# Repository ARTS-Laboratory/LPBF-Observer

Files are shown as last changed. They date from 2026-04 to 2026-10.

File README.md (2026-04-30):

# LPBF-Observer
Hardware and software designs for in situ systems for laser-based powder bed fusion additive manufacturing.

<p align="center">
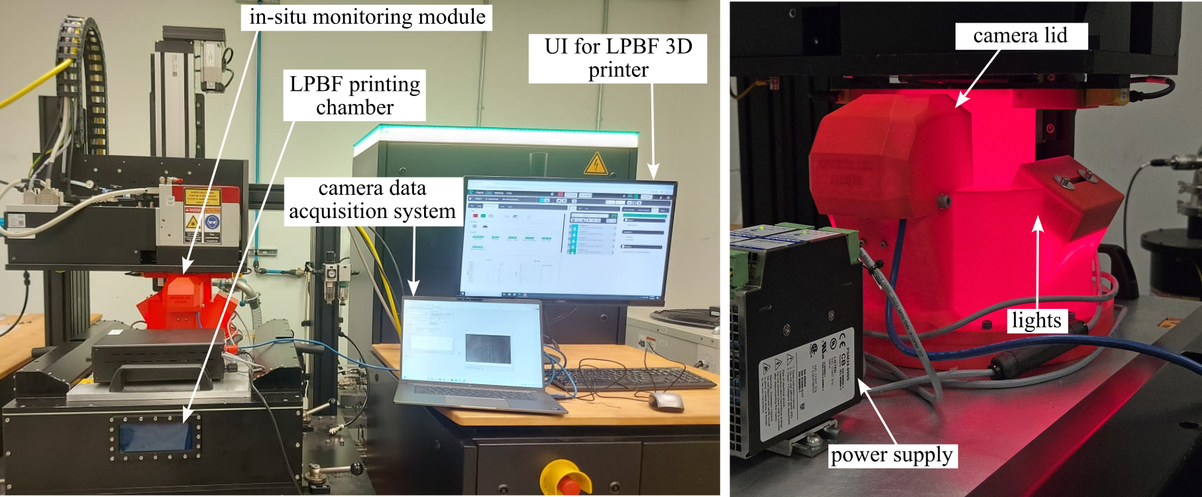
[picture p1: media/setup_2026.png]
 <br> 
The laser vibrometer setup of in situ systems for laser-based powder bed fusion additive manufacturing.  
</p>

## [System Development](system_development)
The system (hardware and software) design for the project.

## [General Use](general_use)
Basic accessories for the system that can be used with any of the covers.

## Licensing and Citation

This work is licensed under a Creative Commons Attribution-ShareAlike 4.0 International License [cc-by-sa 4.0].



#### Bibtex

@Misc{ARTSLabSituMonitoringPowder,  
  author = {{ARTS-L}ab},  
  title  = {{LPBF}-Observer},  
  groups = {{ARTS-L}ab},  
  note = {Accessed: 20xx-xx-xx},  
  url    = {https://github.com/ARTS-Laboratory/LPBF-Observer},  
}  

<p align="center">
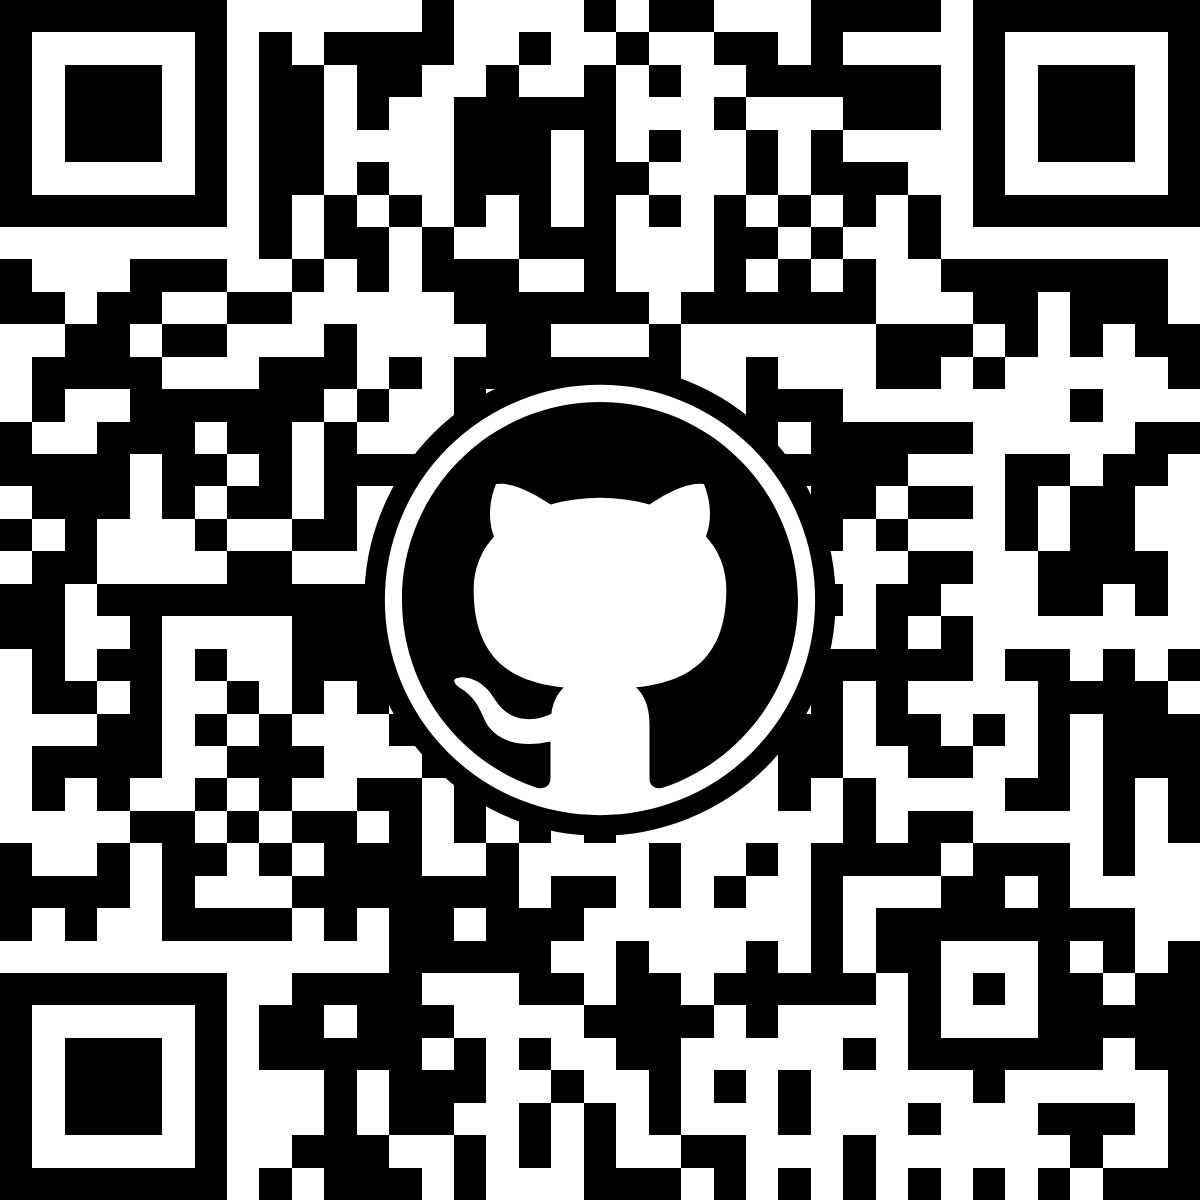
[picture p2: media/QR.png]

</p>
<p align="center">
QR code for repo.
</p>

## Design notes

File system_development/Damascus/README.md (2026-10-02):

# Damascus
Sensing system designed with multiple sensing systems.

## V0.1.0
Dual vision holder designed for thermal and optical cameras 

## V0.2.0
Dual vision holder designed for optical and event cameras 

## V0.3.0
Triple vision holder desinged for optical, thermal, and event cameras 

## V0.4.0
Dual vision holder designed to take a mixture of cameras

## V0.5.0
A more refined dual vision holder designed to take a mixture of cameras
## V0.5.1
Adding distinct software controls for variations of the Damascus setup.

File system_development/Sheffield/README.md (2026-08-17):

# Sheffield
An in situ sensing system with a laser vibrometer.

## V0.1.0 - Exploriotority 
Initial hardware design for in situ monitoring system.

## V0.2.0 - System Built as Sub-components
Initial hardware design for in situ monitoring system.

## V0.3.0 - First Single Prototype
Combining the sub-components of V0.2 into a single hardware design. 

## V0.4.0 
First clean version of a semi-stable lid.

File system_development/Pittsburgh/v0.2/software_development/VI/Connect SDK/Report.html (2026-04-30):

Import Shared Library Report

Friday, May 16, 2025 3:06:13 PM

Your generated files are installed in the following folder:
C:\Users\mayhe\OneDrive\Documents\GitHub\In-situ-monitoring-of-powder-bed-fusion-additive-manufacturing\system_development\Orichalcum\v0.2\Software_design\thermal-camera\VI\Connect SDK

Parsing header file warnings:
No errors/warnings occurred when parsing the header file.

The following errors/warnings occurred when generating the wrapper VIs for this shared library.

Cannot create VI
The following VI cannot be created. This might indicate that the associated function contains parameters of a data type that cannot be converted directly. To work around this issue, you can create a custom control or typedef control to represent a complex structure or multidimensional array, then re-run the Import Shared Library wizard and select Update VIs from a shared library. Using the same shared library, step through the wizard again. On the Configure VIs and Controls page, assign the custom control or typedef to the associated parameter(s). Complex structures include nested structures, structures containing arrays, arrays of strings, and multidimensional arrays.
Get Fixed Emissivity.vi
Init Imager IPC.vi
Release Imager IPC.vi
Run Imager IPC.vi
Set Fixed Emissivity.vi
Set Imager IPC Count.vi

VI Not Executable
The VI is not executable because of one of the following reasons:
1. The shared library or a dependent file is not installed. To make the VI executable, you must install the shared library and all support files on the computer on which you run the VI.
2. A required custom control might be empty or cannot be found. To make the VI executable, update the custom control manually.
3. The VI contains a parameter with an unsupported data type. To make the VI executable, you must replace the empty cluster that the wizard generates with a control or indicator that uses supported data types.
Set Callback On Areas Init.vi
Set Callback On Config Changed.vi
Set Callback On Frame Init.vi
Set Callback On Init Completed.vi
Set Callback On LS Slit Center Line.vi
Set Callback On New Frame.vi
Set Callback On New Visible Frame.vi
Set Callback On Play Metadata.vi
Set Callback On Server Stopped.vi
Set Callback On Visible Frame Init.vi

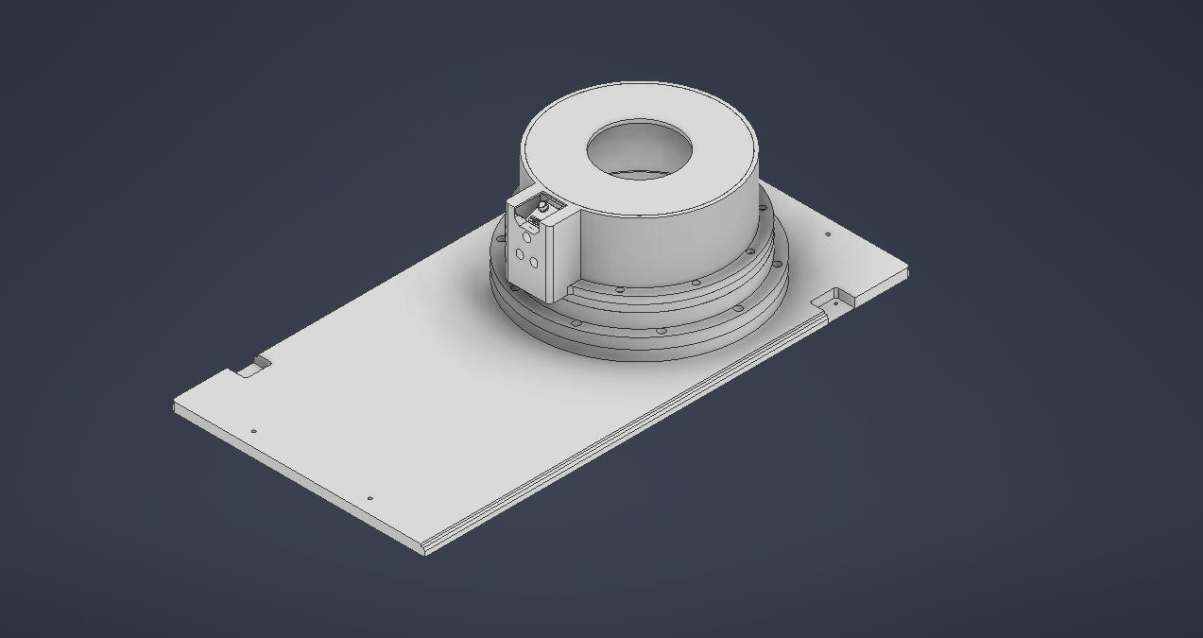
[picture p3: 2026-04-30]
system_development/Birmingham/media/Optical Camera Only.png

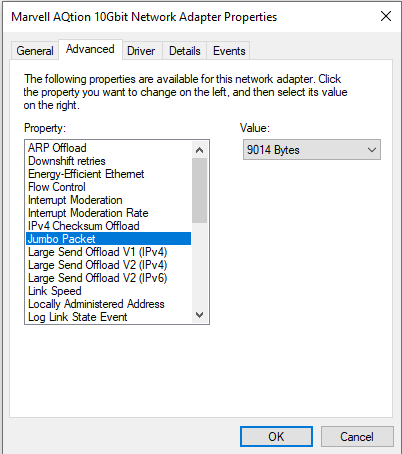
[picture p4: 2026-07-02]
system_development/Damascus/V0.5.1/software development/event_optical/iteration_2/Media/JumboPacket.png

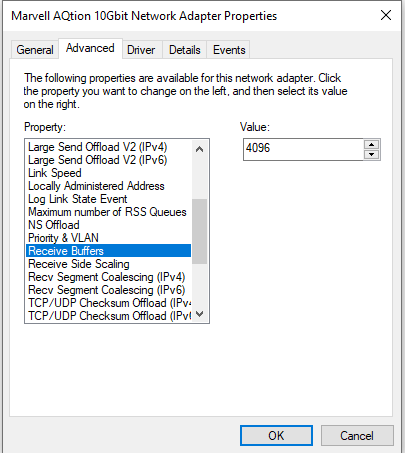
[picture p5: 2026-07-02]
system_development/Damascus/V0.5.1/software development/event_optical/iteration_2/Media/ReceiveBuffers.png

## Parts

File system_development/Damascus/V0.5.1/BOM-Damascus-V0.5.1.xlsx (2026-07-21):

Internal Part Name | MFR / Vendor Description | MFR Part Number | Amount Per Cover | Individual Cost | Total Cost | Notes | Vendor 1 | Vendor 2 | Vendor 3 | Vendor 4 | Vendor 5 | Vendor 6
Aluminum Cover |  |  | 1 | $800.00 | $800.00 | Custom order from Xometry | https://www.xometry.com/
handle | JW WINCO Pull Handle: Unthreaded Holes, Plastic, Black, 1/4 in/5/16 in/M6/M8 Screw Size, 0.32 in | 6333220 | 2 | $12.70 | $25.40 |  | https://www.grainger.com/product/JW-WINCO-Pull-Handle-Unthreaded-Holes-813RC8
rubber seal | Rubber Cord: Buna-N, Round C.S. Shape, 3 mm C.S., 100 ft Overall Lg | CSBUNA-3.0-100 | 1 | $73.29 | $73.29 |  | https://www.grainger.com/product/Rubber-Cord-Buna-N-848F88
Seal Glass Ring |  |  |  |  | $0.00
Cylinder Housing |  |  |  |  | $0.00
Camera Lid |  |  |  |  | $0.00
Cylinder Segment Inner |  |  |  |  | $0.00
Cylinder Segment Outer |  |  |  |  | $0.00
Magnet Sensors | PILZ PSEN 2.1-10 512110 V1.1 |  |  |  | $0.00
M6x14 Socket Head Screw | Socket Head Cap Screw: M6x1.00 Thread Size, 14 mm Lg, Std, Plain, Stainless Steel, 18-8, 50 PK | M51050.060.0014 | 1 | $4.70 | $4.70 |  | https://www.grainger.com/product/Socket-Head-Cap-Screw-M6x1-26WC46
M6x20 Bolt | Socket Head Cap Screw: M6x1.00 Thread Size, 20 mm Lg, Std, Plain, Stainless Steel, 18-8, 50 PK | M51050.060.0020 | 1 | $7.58 | $7.58 |  | https://www.grainger.com/product/Socket-Head-Cap-Screw-M6x1-26WC48
M6 ID 12mm OD Washer | Flat Washer: 18-8, Stainless Steel, M6 Screw Sz, 6.62 mm In Dia, 12 mm Out Dia, 18-8, 50 PK | M51420.060.0001 | 1 | $1.54 | $1.54 |  | https://www.grainger.com/product/Flat-Washer-18-8-26WC34
M6 Nut | Hex Nut: Std Hex, M6x1.00 Thread, 10 mm Hex Wd, 5 mm Hex Ht, Stainless Steel, 18-8, Plain, 50 PK | M51080.060.0001 | 1 | $2.95 | $2.95 |  | https://www.grainger.com/product/Hex-Nut-Std-Hex-22YK33
M5x40 Bolt |  |  |  |  | $0.00
M5 ID 9.8mm OD Washer |  |  |  |  | $0.00
M4x14 Bolt |  |  |  |  | $0.00
M4 ID 8.8mm OD Washer |  |  |  |  | $0.00
M3x25 Bolt |  |  |  |  | $0.00
M3x10 Pan Head Bolt |  |  |  |  | $0.00
M3 Washer |  |  |  |  | $0.00
M3 Nuts |  |  |  |  | $0.00
USB hub | Eaton Tripp Lite Series 4-Port Industrial-Grade USB 3.x (5Gbps) Hub - 20 kV ESD Immunity, Metal Housing, Mountable | U360-004-IND | 1 | $110.00 | $110.00 |  | https://www.cdwg.com/product/tripp-lite-4-port-industrial-usb-3.0-superspeed-hub-15kv-esd-immunity-metal/3682489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
relays | RELAY GEN PURPOSE SPST 6A 24V | 2903361 | 2 | $9.46 | $18.92 |  | https://www.digikey.com/en/products/detail/phoenix-contact/2903361/4755334
USB-C to USB-A Adapter | Eaton Tripp Lite Series USB 3.0 Adapter Converter USB-A to USB Type C M/F USB-C - USB-C adapter - USB A to 24 pin USB-C | U329-000 | 1 | $13.96 | $13.96 |  | Eaton Tripp Lite Series USB 3.0 Adapter Converter USB-A to USB Type C M/F USB-C - USB-C adapter - USB A to 24 pin USB-C - U329-000 - USB Adapters - CDWG.com (https://www.cdwg.com/product/tripp-lite-usb-3.0-adapter-converter-usb-a-to-usb-type-c-m-f-usb-c/5238658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)
Light | 2X3 SPOT LIGHT | AL143W-625IC | 2 | $695.33 | $1390.66 | Used off Ebay is a good source | CIMTEC Automation
Eathnet hub power sully | AC or DC DIN Rail Power Supply 1 Output 48V 1.6A | XDR-75E-48 | 1 | $23.00 | $23.00 |  | https://www.digikey.com/en/products/detail/mean-well-usa-inc/XDR-75E-48/26080802
2.5G PoE++ DIN-Rail Switch | TRENDnet TI-BG50611 6-Port Industrial 2.5G PoE++ DIN-Rail Switch with 10G Ports | TI-BG50611 | 1 | $329.00 | $329.00 |  | https://www.newegg.com/trendnet-ti-bg50611/p/0XP-001A-009D1?Item=9SIAHFEKFX4055
switch to thunderbold patch cable | Eaton Tripp Lite Series Cat6a 10G Snagless Shielded Slim STP Ethernet Cable (RJ45 M/M), PoE, Blue, 3 ft. (0.9 m) | 7175130 | 1 | $8.47 | $8.47 |  | https://www.cdwg.com/product/eaton-tripp-lite-series-cat6a-10g-snagless-shielded-slim-stp-ethernet-cable/7175130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
10 GBE to Thunderbolt adapter | OWC Thunderbolt 4 10G Ethernet Adapter | OWCTB4ADP10GBE | 1 | $181.53 | $181.53 |  | https://www.cdwg.com/product/owc-thunderbolt-4-10g-ethernet-adapter/8482162
2M Thunderbolt cable | OWC 2.0M (78") Thunderbolt 4 (USB-C) Cable for Thunderbolt And USB-C Devices - Black | OWCCBLTB4C2.0M | 1 | $49.29 | $49.29 |  | https://www.cdwg.com/product/owc-2.0m-78-thunderbolt-4-usb-c-cable-for-thunderbolt-and-usb-c-device/7390529
1M Thunderbolt cable | OWC 1.0M (39.4") Thunderbolt 5 (USB-C) Cable Black for Thunderbolt And USB-C Devices - Black | OWCCBLTB5C1.0M | 1 | $30.51 | $30.51 |  | https://www.cdwg.com/product/owc-1.0m-39.4-thunderbolt-5-usb-c-cable-black-for-thunderbolt-and-usb/8269345
Thermal Camera | Optris Xi 400 thermal camera, 382 x 288, 18 deg x 14 deg lens, f = 20 mm | OPTXI40LTF20T090 | 1 | $2995.00 | $2995.00 | Optional thermal-imaging configuration from paper; includes PIX Connect software/cables per vendor listing. | https://www.tequipment.net/Optris/XI400-18x14/Scientific-Thermal-Imagers/ | https://optris.com/us/products/thermal-cameras/compact-line/xi-400/ | https://www.newark.com/optris/optxi40ltf20t090/thermal-imager-382-x-288-20mm/dp/70AJ6214
Optical Camera - USB3 | BFS-U3-200S6M-C USB 3.1 Blackfly S monochrome camera, 20 MP, 1 in Sony IMX183, C-Mount | BFS-U3-200S6M-C | 1 | $700.00 | $700.00 | Primary optical camera from paper; note that camera accessories/cables may be sold separately. | https://www.edmundoptics.com/p/BFS-U3-200S6M-C-USB3-Blackflyreg-S-Monochrome-Camera/40177/ | https://www.digikey.com/en/products/detail/flir-integrated-imaging-solutions-inc/BFS-U3-200S6M-C/16528419
Optical Camera - GigE/PoE Alternate | BFS-PGE-200S6M-C PoE GigE Blackfly S monochrome camera, 20 MP, 1 in Sony IMX183, C-Mount | BFS-PGE-200S6M-C | 1 | $700.00 | $700.00 | Optional alternate from supplied eBay link; set Amount Per Cover to 1 if selecting the PoE/GigE camera instead of USB3. | https://www.edmundoptics.com/p/bfs-pge-200s6m-c-poe-gige-blackflyr-s-monochrome-camera/40195/ | https://www.ebay.com/itm/388858412191 | https://www.digikey.com/en/products/detail/flir-integrated-imaging-solutions-inc/BFS-PGE-200S6M-C/16528297
35 mm Lens - 1 in Sensor | Edmund Optics 35 mm focal length HP Series fixed focal length lens, C-Mount, f/1.8, 1.1 in max sensor format | 86-573 | 1 | $660.00 | $660.00 | Primary high-resolution optical lens for the 1 in/20 MP camera; supplied eBay 86573 listing maps to Edmund stock #86-573. | https://www.edmundoptics.com/p/35mm-focal-length-hp-series-fixed-focal-length-lens/28992/ | https://www.ebay.com/itm/334656600752
35 mm Lens - 2/3 in Alternate | Edmund Optics 35 mm C Series fixed focal length lens, C-Mount, f/1.65, 2/3 in max sensor format | 59-872 | 1 | $374.00 | $374.00 | Optional older/used lens from duplicate eBay link; not counted in total unless selected. eBay sold listing showed $49.99. | https://www.edmundoptics.com/p/35mm-c-series-fixed-focal-length-lens/16529/ | https://www.ebay.com/itm/377073297097
Lens Step-Up Adapter | Midwest Optical Systems Step-Up Adapter M25.5-M37 | SU25.5-37 | 1 | $30.00 | $30.00 | Use with the #59-872 C Series lens to mount M37 filters; not needed for the #86-573 HP lens with native M37 thread. | https://machinevisiondirect.com/products/midopt-su25_5-37?variant=37662128013502
Bandpass Filter - Dark Red 660 nm | Midwest Optical Systems BP660-37 dark red bandpass filter, M37 x P0.75 | BP660-37 | 1 | $151.00 | $151.00 | Paper-specified dark red bandpass filter; use with 650-680 nm red lighting. | https://machinevisiondirect.com/products/mid-bp660-37 | https://midopt.com/filters/bp660/
Bandpass Filter - Light Red 635 nm | Midwest Optical Systems BP635-37 light red bandpass filter, M37 x P0.75 | BP635-37 | 1 | $151.00 | $151.00 | Optional light-red filter from supplied link; set Amount Per Cover to 1 for 615-645 nm lighting. | https://machinevisiondirect.com/products/mid-bp635-37 | https://midopt.com/filters/bp635/
37 mm UV Protective Lens Filter | Tiffen UV Protector Filter, 37 mm | 37UVP | 1 | $9.99 | $9.99 | Plain protective UV filter for 37 mm lens/filter thread | Tiffen
 |  |  |  | Total | $8841.79

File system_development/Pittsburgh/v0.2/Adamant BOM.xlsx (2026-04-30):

Name | Quantity | Source
Aluminum Cover | 1 | Xometry + model
Pull Handle | 2 | https://www.grainger.com/product/JW-WINCO-Pull-Handle-Unthreaded-Holes-813RC8
Horsehoe | 1 | Xometry + model
Head Plate (metal) | 1 | Xometry + model
Welding glass | 1 | Laser Vision (https://lasersafety.com/product/p5p10-window/) | Glass1 (https://www.mscdirect.com/product/details/62674445) | Glass2 (https://www.mscdirect.com/product/details/62674403) | Glass3 (https://www.mscdirect.com/product/details/62674437) | Glass4 (https://www.mscdirect.com/product/details/62674411)
Xi 400 20mm | 1 | optris
Seal Glass Ring | 1 | 3D Printed
Cylinder Housing | 1 | 3D Printed
Camera Lid | 1 | 3D Printed
Cylinder Segment Inner | 1 | 3D Printed
Cylinder Segment Outer | 1 | 3D Printed
Magnet Sensors | 4 | Aconity
M6x15 | 2
M6x20 | 5
M6 ID 11.8mm OD Washer | 7
M6 Nut | 3
M5x40 | 12
M5x20 | 1
M5 ID 9.8mm OD Washer | 16
M5 Nut | 4
M4x14 | 11
M4 ID 8.8mm OD Washer | 11
Rubber Seal (100ft) | 1 | https://www.grainger.com/product/Rubber-Cord-Buna-N-848F88

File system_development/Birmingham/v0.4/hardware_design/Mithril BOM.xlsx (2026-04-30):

Name | Quantity | Source
Aluminum Cover | 1 | Xometry + model
Pull Handle | 2 | https://www.grainger.com/product/JW-WINCO-Pull-Handle-Unthreaded-Holes-813RC8
Head Plate (metal) | 1 | Xometry + model
FLIR Blackfly Camera | 1
Edmunds Optis 25mm Lens | 1
Seal Glass Ring | 1 | 3D Printed
Cylinder Housing | 1 | 3D Printed
Camera Lid | 1 | 3D Printed
Cylinder Segment Inner | 1 | 3D Printed
Cylinder Segment Outer | 1 | 3D Printed
Magnet Sensors | 4 | Aconity
M6x15 Bolt | 2
M6x20 Bolt | 4
M6 ID 11.8mm OD Washer | 6
M6 Nut | 2
M5x40 Bolt | 12
M5 ID 9.8mm OD Washer | 15
M4x14 Bolt | 11
M4 ID 8.8mm OD Washer | 11
M3x25 Bolt | 3
M3x10 Pan Head Bolt | 4
M3 Washer | 4
M3 Nuts | 4
Rubber Seal (100ft) | 1 | https://www.grainger.com/product/Rubber-Cord-Buna-N-848F88

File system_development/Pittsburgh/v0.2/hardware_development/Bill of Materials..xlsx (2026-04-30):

Name | Quantity | Source 1 | Source 2 | Source 3
Cover | 1 | Xometry + model
300mm Housing 1 | 1 | 3D Printed
300mm Housing 2 | 1 | 3D Printed
Cylinder Spacer | 1 | 3D Printed
Cylinder Segment Inner | 1 | 3D Printed
Cylinder Segment Outer | 1 | 3D Printed
Cylinder Segment 1 | 1 | 3D Printed
Cylinder Segment Face | 1 | 3D Printed
Camera Bracket | 1 | 3D Printed
Flir Camera Blackfly | 1 | Teledyne Flir Blackfly S USB3 1.6MP Color Camera BFS-U3-16S2C-CS (https://www.bhphotovideo.com/c/product/1844599-REG/teledyne_flir_bfs_u3_16s2c_cs_blackfly_s_usb3_1_6mp.html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)
Welding glass | 1 | Laser Vision (https://lasersafety.com/product/p5p10-window/) | Glass1 (https://www.mscdirect.com/product/details/62674445) | Glass2 (https://www.mscdirect.com/product/details/62674403) | Glass3 (https://www.mscdirect.com/product/details/62674437) | Glass4 (https://www.mscdirect.com/product/details/62674411)
Cover ^ 2 | 1 | 3D Printed
Cover ^ 3 | 1 | 3D Printed
Cylinder Segment Holder | 1 | 3D Printed
Head Plate (metal) | 1 | Xometry + model
M6 x 10 | 4 | M6-1 Thread Size, 10 mm Lg, Socket Head Cap Screw - 26LG36|M07000.060.0010 - Grainger (https://www.grainger.com/product/Socket-Head-Cap-Screw-M6-1-26LG36)
M4 x 14 | 2 | M4-0.7 Thread Size, 14 mm Lg, Socket Head Cap Screw - 4XY51|SC2204014-100P - Grainger (https://www.grainger.com/product/Socket-Head-Cap-Screw-M4-0-4XY51)
M5 x 20 | 10 | https://www.grainger.com/product/Socket-Head-Cap-Screw-M5-0-26LG28
M5 x 50 | 9 | M5-0.8 Thread Size, 50 mm Lg, Socket Head Cap Screw - 6CE82|M07000.050.0050 - Grainger (https://www.grainger.com/product/Socket-Head-Cap-Screw-M5-0-6CE82)
M5 x 16 | 10 | M5-0.8 Thread Size, 16 mm Lg, Socket Head Cap Screw - 23NN83|M51050.050.0016 - Grainger (https://www.grainger.com/product/Socket-Head-Cap-Screw-M5-0-23NN83)
M4 x 12 | 14 | https://www.grainger.com/product/Socket-Head-Cap-Screw-M4-0-22UC39
M3 x 16 | 2 | https://www.grainger.com/product/Socket-Head-Cap-Screw-M3-0-22TZ13
M3 x 8 | 3 | https://www.grainger.com/product/Socket-Head-Cap-Screw-M3-0-22TY48
M3 x 35 | 2 | https://www.grainger.com/product/Socket-Head-Cap-Screw-M3-0-22UC31
M3 x 25 | 1 | https://www.grainger.com/product/Socket-Head-Cap-Screw-M3-0-22UC28
M5 nut | 21 | https://www.grainger.com/product/Hex-Nut-M5-0-80-Thread-22YK31
M3 nut | 3 | https://www.grainger.com/product/Hex-Nut-M3-0-50-Thread-6CA29
M4 nut | 2 | https://www.grainger.com/product/Hex-Nut-M4-0-70-Thread-22UK82
Pull Handle | 2 | https://www.grainger.com/product/JW-WINCO-Pull-Handle-Unthreaded-Holes-813RC8
Rubber Seal | 1 | https://www.grainger.com/product/Buna-N-Round-Cord-Buna-N-6RTT7

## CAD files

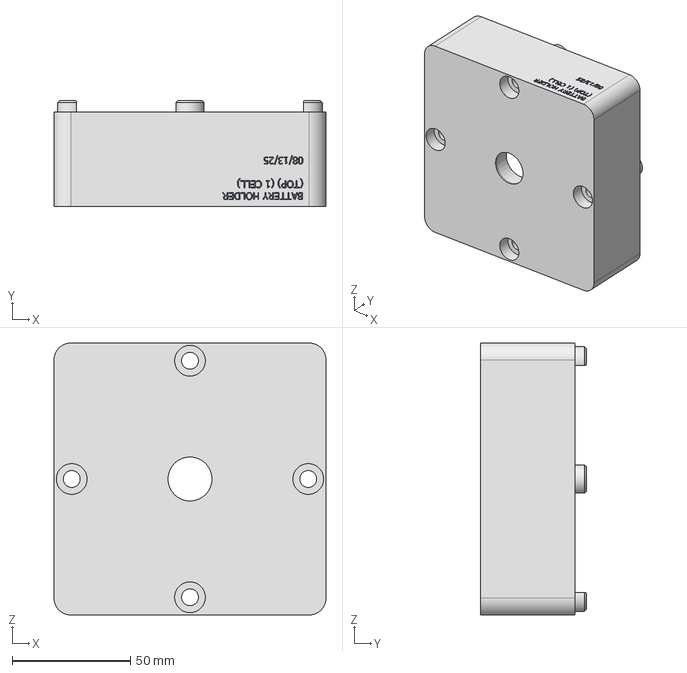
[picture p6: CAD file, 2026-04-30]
general_use/Battery Holder/STEP files/Battery Holder (Top) 1 Cell.stp
115.0 x 45.0 x 115.0 mm

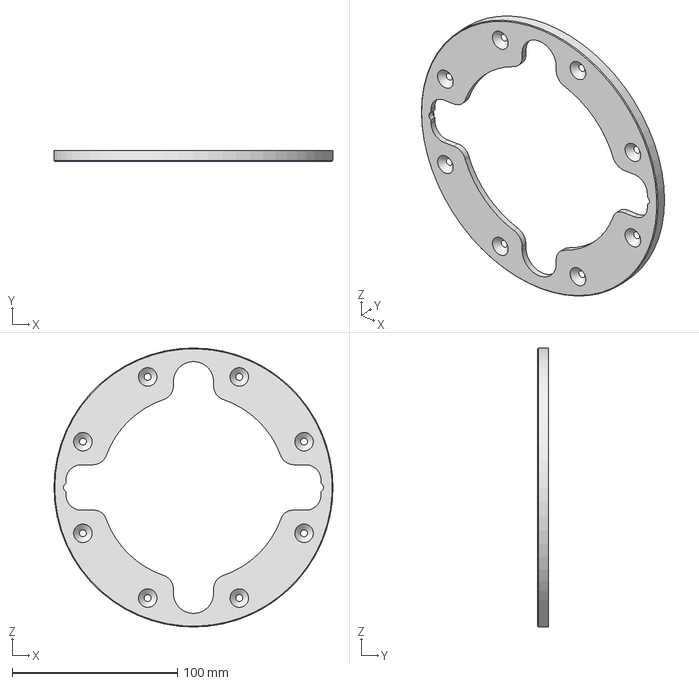
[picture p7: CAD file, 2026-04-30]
general_use/Build platform/Clamp Ring.stp
169.0 x 6.50 x 169.0 mm

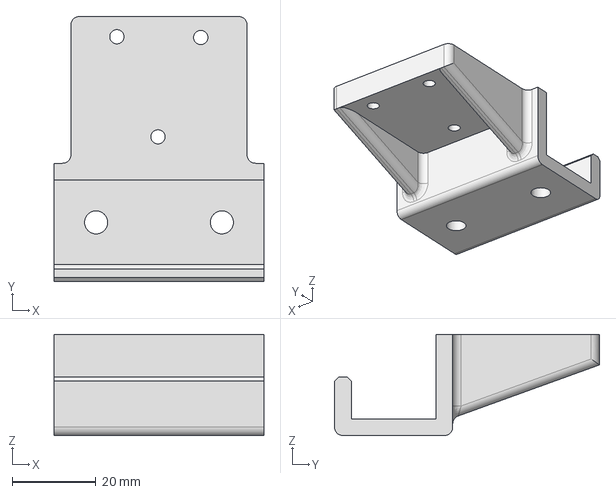
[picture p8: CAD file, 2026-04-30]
general_use/Camera Beam Mount/Optical Camera 8020 Bracket.stp
50.0 x 63.2 x 24.1 mm

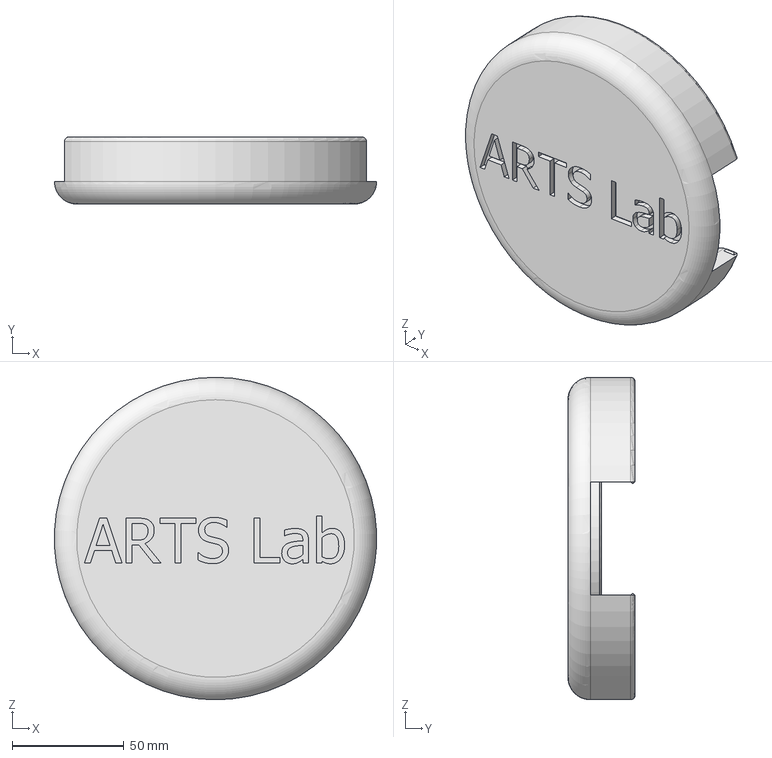
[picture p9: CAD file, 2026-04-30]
general_use/Head Plate Parts/STEP/Access Cap.stp
143.8 x 30.0 x 144.0 mm

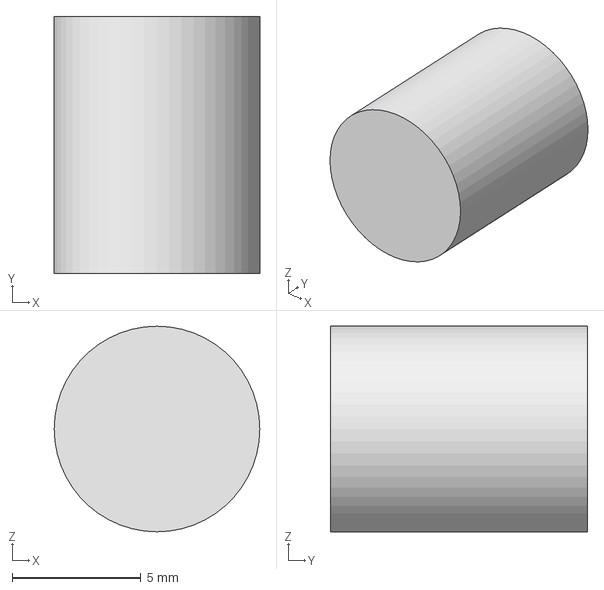
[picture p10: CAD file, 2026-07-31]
general_use/Reference Prints/Associated models/Circle.stp
8.00 x 10.0 x 8.00 mm

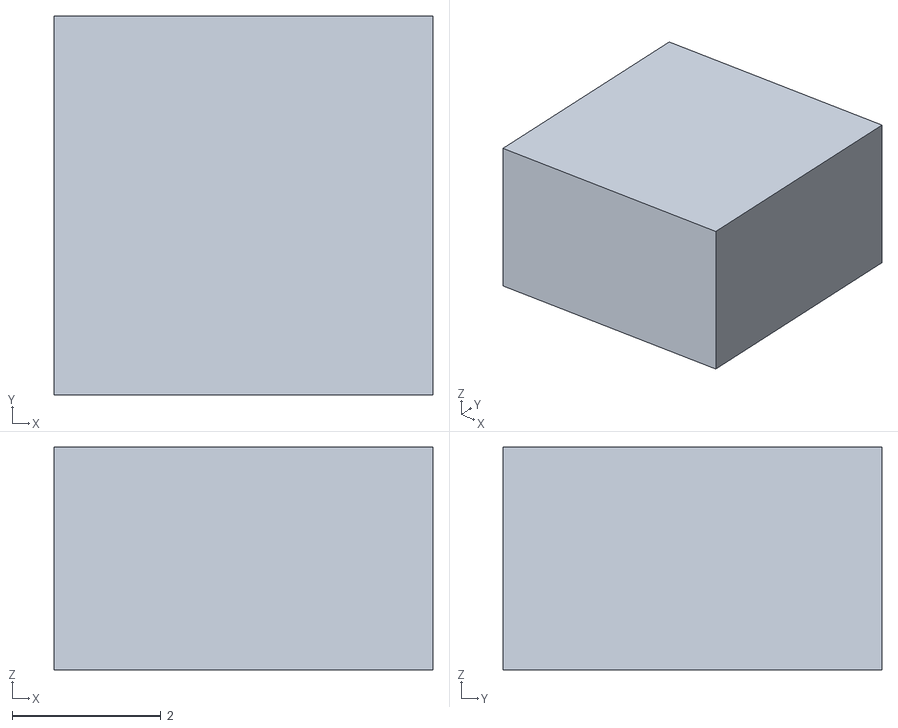
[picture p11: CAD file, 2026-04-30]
general_use/Reference Prints/shape-square.stl
5.10 x 5.10 x 3.00

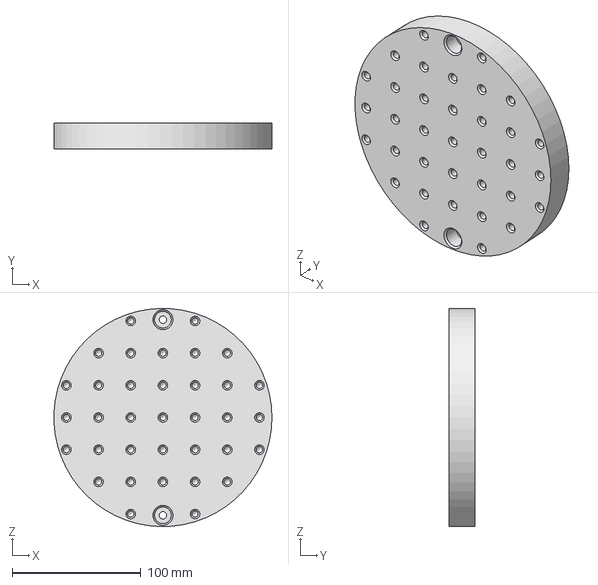
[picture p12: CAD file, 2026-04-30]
general_use/Threaded Build Plate/substrate plate With Lots of holes.stp
169.4 x 20.0 x 169.4 mm

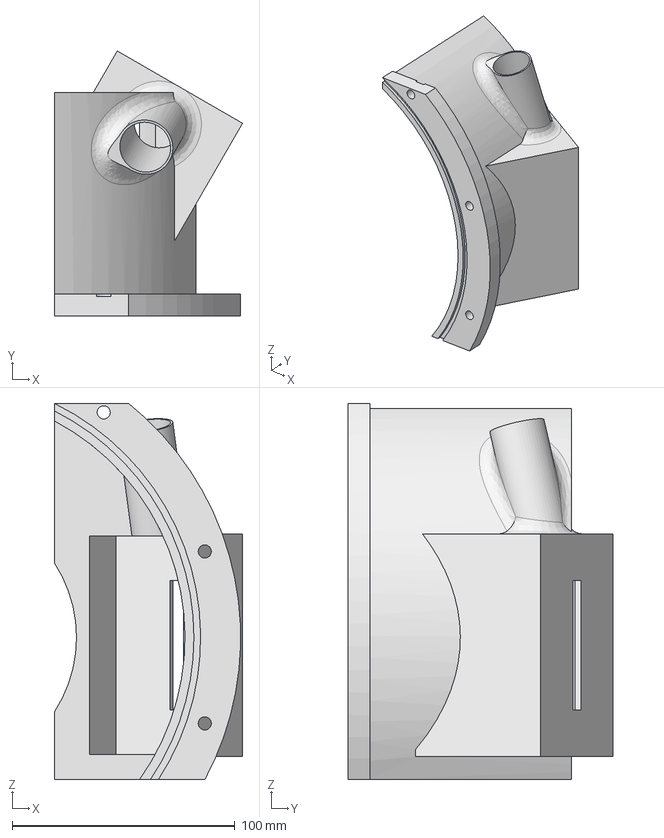
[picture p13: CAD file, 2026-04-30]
system_development/Birmingham/v0.4/hardware_design/STEP Files/Camera Cylinder Housing - Red Lights Test.stp
84.5 x 119.1 x 169.0 mm

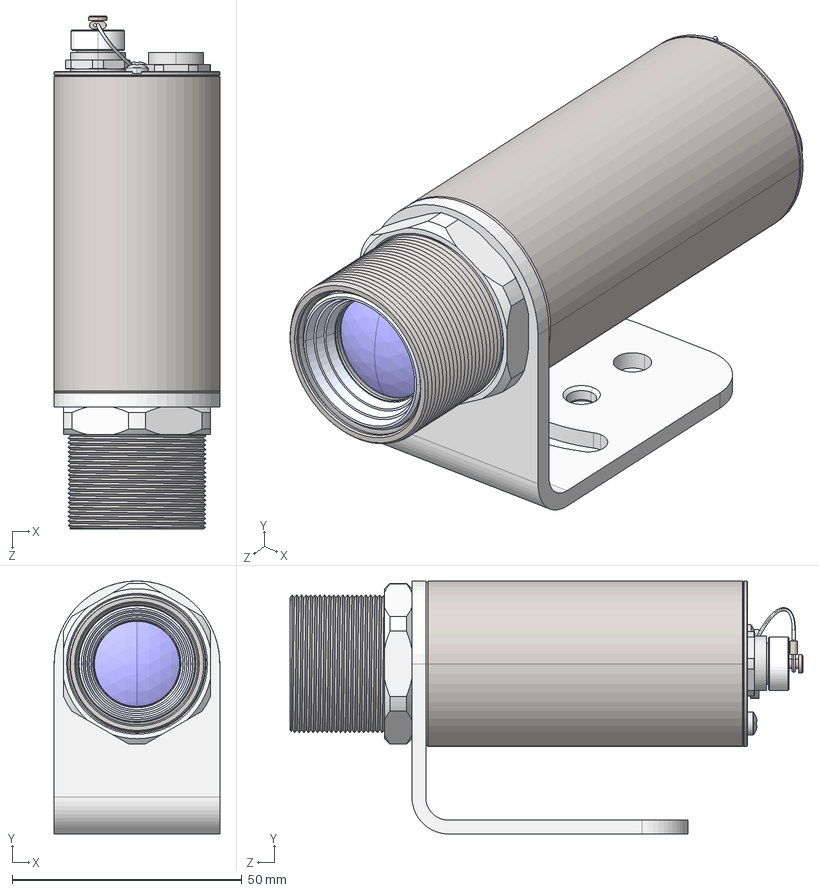
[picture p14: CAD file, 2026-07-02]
system_development/Damascus/V0.5.1/hardware development/Parts/Xi-410-Camera-with-29°-x-18°-Lens/Xi 410 Camera with 29° x 18° Lens.step
36.0 x 55.0 x 111.5 mm
1R001-3 Gehäuserohr-384 x 2
1R002 Rückwand
9P834-1B RW-LP-2Bu-8p-5p
61253 Linsenschraube KS DIN 7985 VZ M2,5x3 x 2
63001 O-Ring NBR 2,5 x 1_O-Ring 2,5 x 1
63033 O-Ring 33,5 x 1_O-Ring 38 x 1,5
51101 Schutzkappe-712 FD
63118 O-Ring 18,5x1,5
1R085-B Linse2-F13-384-GE-p17-RevB
1R022-16 Frontschraubring-429-III
63125 O-Ring 25,5x1,5
1C517 Mutter M30x1
1R029 Montagewinkel-Xi

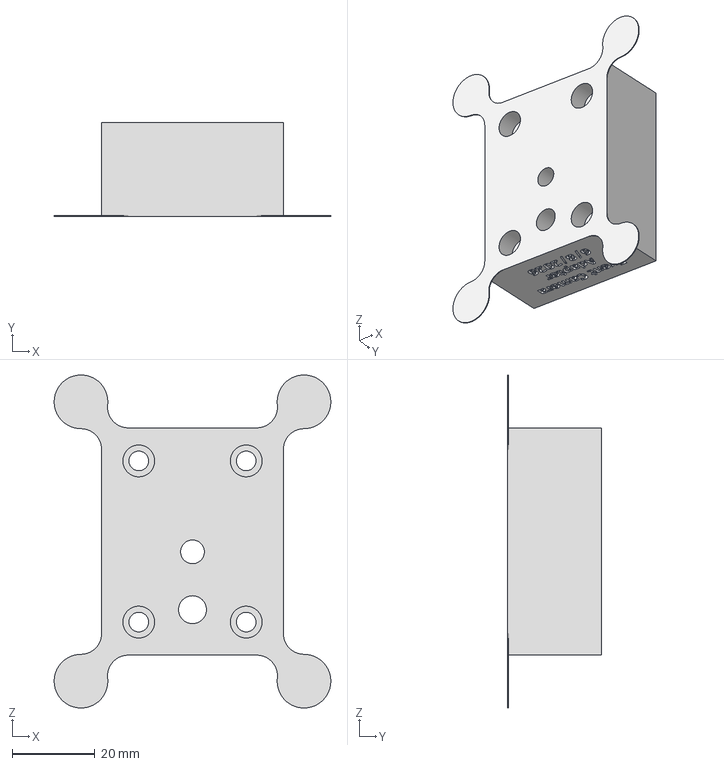
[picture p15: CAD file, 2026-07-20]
system_development/Damascus/V0.5.1/hardware development/Step Files/adapter-event.stp
67.0 x 22.7 x 80.6 mm

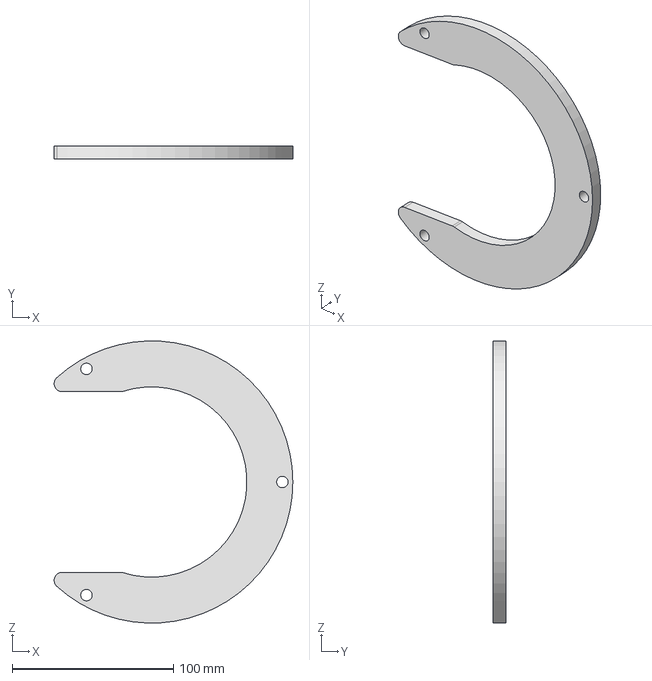
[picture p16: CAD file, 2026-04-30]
system_development/Pittsburgh/v0.2/hardware_development/STEP Files/Horse Shoe .stp
148.0 x 8.00 x 174.9 mm

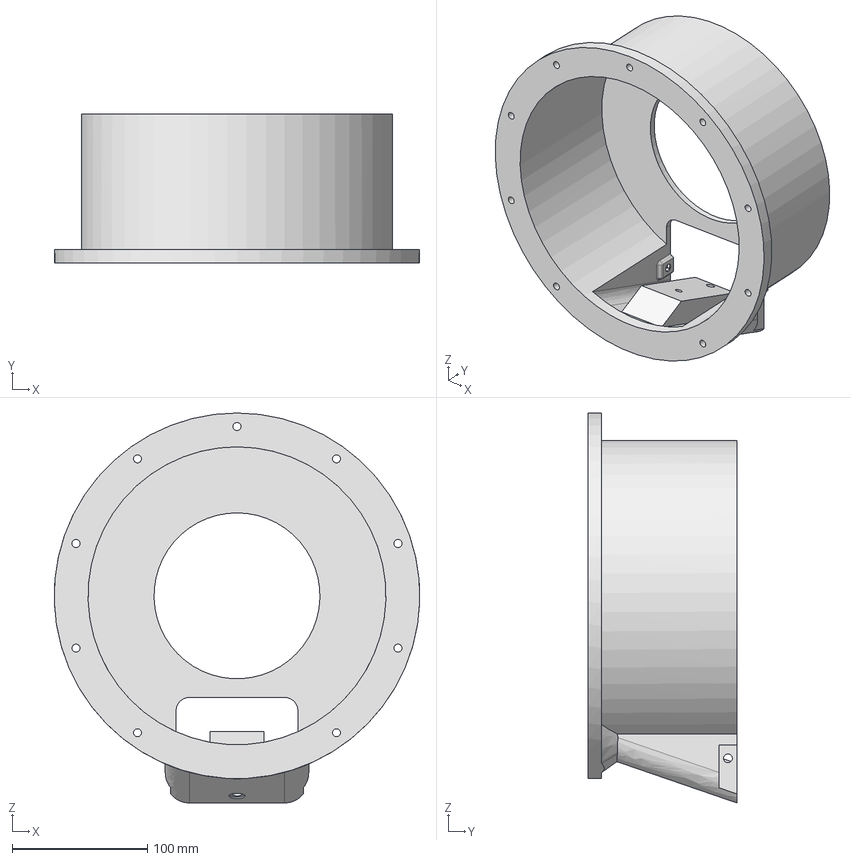
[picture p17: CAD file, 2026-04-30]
system_development/Sheffield/v0.4.0/Vibrometer Housing.stp
269.9 x 110.0 x 288.0 mm

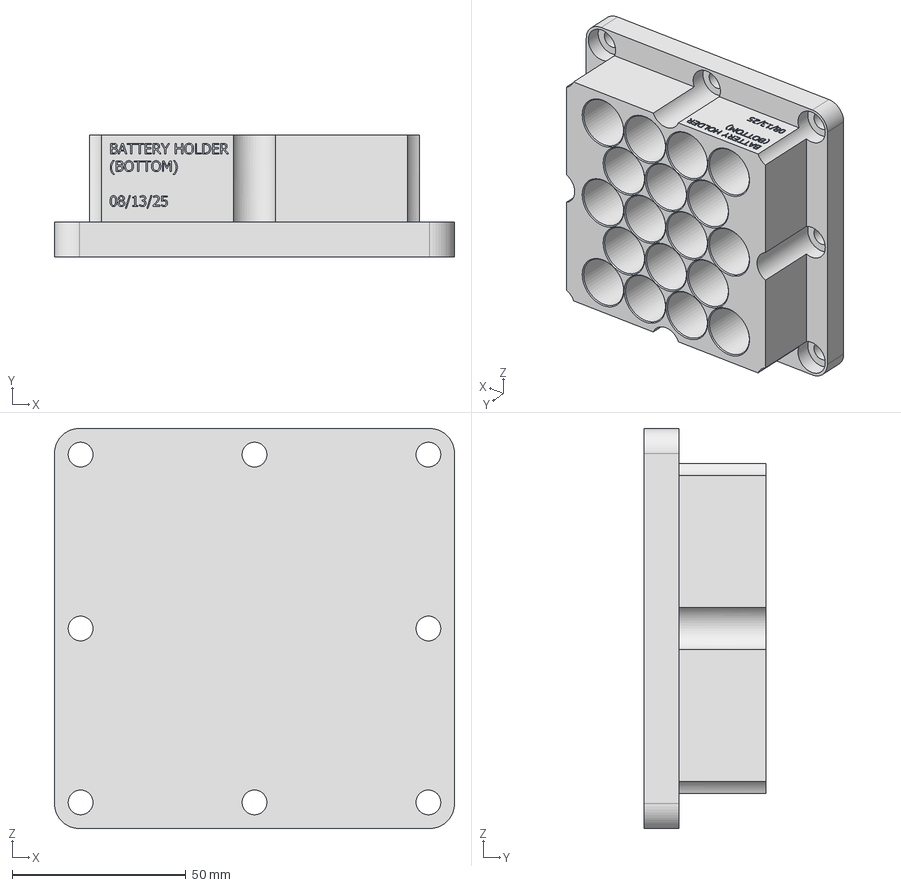
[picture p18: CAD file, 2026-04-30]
general_use/Battery Holder/STEP files/Battery Holder (Bottom).stp
115.0 x 35.0 x 115.0 mm

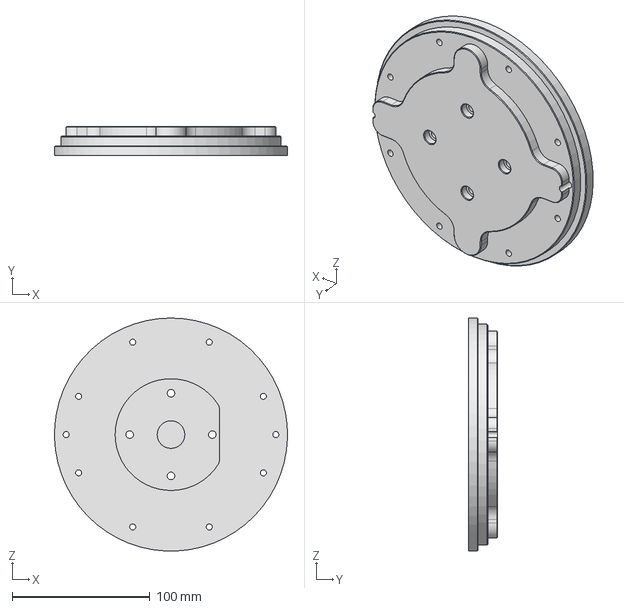
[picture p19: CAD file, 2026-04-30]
general_use/Build platform/Updated Build Platform.stp
168.9 x 21.0 x 168.9 mm

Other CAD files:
general_use/Head Plate Parts/STEP/Head Plate Insert.stp
general_use/Reference Prints/Associated models/Rounded Square.stp
general_use/Reference Prints/Flower.stl
system_development/Birmingham/v0.4/hardware_design/STEP Files/Optical Lid.stp
general_use/Aconity 3D Models/Printer/Build Plate.ipt
general_use/Aconity 3D Models/Printer/Cover.ipt
general_use/Aconity 3D Models/Printer/Cylinders.ipt
general_use/Aconity 3D Models/Printer/Laser w_ silver v4.iam
general_use/Aconity 3D Models/Printer/Printer Assembly.iam
general_use/Aconity 3D Models/Printer/Printer Body v6.ipt
general_use/Aconity 3D Models/Printer/Printer Cover v10.iam
general_use/Aconity 3D Models/Printer/Printer Frame.ipt
general_use/Aconity 3D Models/Printer/PrinterHeadLip_RightSide.ipt
general_use/Aconity 3D Models/Printer/Silver.ipt
general_use/Aconity 3D Models/Printer/overhead laser unit v1.ipt
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

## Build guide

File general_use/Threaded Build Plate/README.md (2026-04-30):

# Threaded build-plate

A threaded build plate for the laser welding system.

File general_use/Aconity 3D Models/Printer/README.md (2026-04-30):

# Aconity MIDI – 3D Reference Models
Assembly of the printer we are working with.

<p align="center">
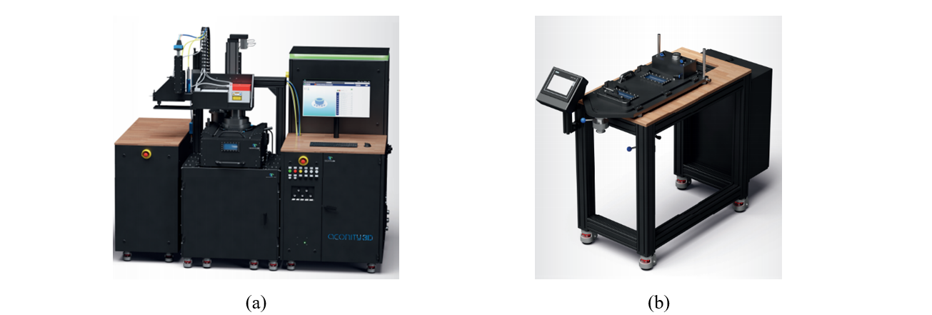
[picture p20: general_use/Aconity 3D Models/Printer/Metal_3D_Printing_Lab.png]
Figure Caption
  
</p>

**Figure 1:** Aconity MIDI Metal 3d printer, showing the: (a) Aconity MIDI, metal LPBFAM printer, and; (b)
sieve station for powder recycling.

## Cover
* The cover or lid for the printer (no cylinder)

## Laser w/ Silver
* Laser platform assembly

## Inner chamber piece
* Piece that adds new powder over the previous layer

## Overhead Laser Unit
* Laser unit, a part of Laser w/ Silver assembly

## Silver 
* Rail that the laser unit rides on

## Cylinders
* Contains the telescoping rings that mate with the laser assembly

## Printer Assembly
* Full printer assembly with all parts

## Printer Body 
* Printer chamber

## Printer Cover
* Cover assembly with Cylinder

## Printer Frame 
* Many parts are attached to the frame

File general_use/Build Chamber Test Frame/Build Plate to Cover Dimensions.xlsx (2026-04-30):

Leg | 263.5
Length Beam | 40
Build Plate | 15
Build Platform | 21
Piezo | 16
Adapter Height | 26.5
Cover to Plate | 145

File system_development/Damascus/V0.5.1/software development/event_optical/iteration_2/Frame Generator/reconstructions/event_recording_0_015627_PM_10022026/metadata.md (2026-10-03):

# event_recording_0_015627_PM_10022026

## Recording Metadata

- **Acquisition Mode**: `Continuous`
- **Arena Api Version**: `unknown`
- **Camera Model**: `TRT009S-E`
- **Duration Seconds**: `8.83006477355957`
- **Erc Enable**: `False`
- **Erc Rate Limit**: `20.0`
- **Event Format**: `EVT3_0`
- **Event Rate**: `101622.01784599925`
- **Height**: `720`
- **Recorded**: `015627_PM_10022026`
- **Recording Triggered**: `True`
- **Requested Stream Buffer Count**: `128`
- **Serial Number**: `250200198`
- **Software**: `Event Camera Recorder`
- **Software Version**: `0.2`
- **Stream Armed Duration Seconds**: `9.78967833518982`
- **Stream Auto Packet Size**: `True`
- **Stream Buffer Handling Mode**: `OldestFirst`
- **Stream Output**: `XYTPFrame`
- **Stream Packet Resend**: `True`
- **Total Buffers**: `7120`
- **Total Events**: `897329`
- **Warmup Buffers Discarded**: `777`
- **Warmup Duration Seconds**: `0.959613561630249`
- **Warmup Event Count Required**: `150000`
- **Warmup Events Discarded**: `150070`
- **Width**: `1280`

## Dataset Information

- **Shape:** `(897329,)`
- **Dtype:** `[('x', '<u2'), ('y', '<u2'), ('t', '<u8'), ('p', 'u1')]`

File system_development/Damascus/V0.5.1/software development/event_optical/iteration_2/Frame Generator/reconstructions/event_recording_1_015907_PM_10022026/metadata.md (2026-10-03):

# event_recording_1_015907_PM_10022026

## Recording Metadata

- **Acquisition Mode**: `Continuous`
- **Arena Api Version**: `unknown`
- **Camera Model**: `TRT009S-E`
- **Duration Seconds**: `11.448554277420044`
- **Erc Enable**: `False`
- **Erc Rate Limit**: `20.0`
- **Event Format**: `EVT3_0`
- **Event Rate**: `98128.37261170472`
- **Height**: `720`
- **Recorded**: `015907_PM_10022026`
- **Recording Triggered**: `True`
- **Requested Stream Buffer Count**: `256`
- **Serial Number**: `250200198`
- **Software**: `Event Camera Recorder`
- **Software Version**: `0.2`
- **Stream Armed Duration Seconds**: `12.47029709815979`
- **Stream Auto Packet Size**: `True`
- **Stream Buffer Handling Mode**: `OldestFirst`
- **Stream Output**: `XYTPFrame`
- **Stream Packet Resend**: `True`
- **Total Buffers**: `9264`
- **Total Events**: `1123428`
- **Warmup Buffers Discarded**: `790`
- **Warmup Duration Seconds**: `1.021742820739746`
- **Warmup Event Count Required**: `150000`
- **Warmup Events Discarded**: `150161`
- **Width**: `1280`

## Dataset Information

- **Shape:** `(1123428,)`
- **Dtype:** `[('x', '<u2'), ('y', '<u2'), ('t', '<u8'), ('p', 'u1')]`

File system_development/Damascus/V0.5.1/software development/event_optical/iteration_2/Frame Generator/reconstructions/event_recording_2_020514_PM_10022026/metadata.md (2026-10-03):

# event_recording_2_020514_PM_10022026

## Recording Metadata

- **Acquisition Mode**: `Continuous`
- **Arena Api Version**: `unknown`
- **Camera Model**: `TRT009S-E`
- **Duration Seconds**: `15.026267051696777`
- **Erc Enable**: `False`
- **Erc Rate Limit**: `20.0`
- **Event Format**: `EVT3_0`
- **Event Rate**: `104477.97810319923`
- **Height**: `720`
- **Recorded**: `020514_PM_10022026`
- **Recording Triggered**: `True`
- **Requested Stream Buffer Count**: `256`
- **Serial Number**: `250200198`
- **Software**: `Event Camera Recorder`
- **Software Version**: `0.2`
- **Stream Armed Duration Seconds**: `15.983316659927368`
- **Stream Auto Packet Size**: `True`
- **Stream Buffer Handling Mode**: `OldestFirst`
- **Stream Output**: `XYTPFrame`
- **Stream Packet Resend**: `True`
- **Total Buffers**: `12442`
- **Total Events**: `1569914`
- **Warmup Buffers Discarded**: `771`
- **Warmup Duration Seconds**: `0.9570496082305908`
- **Warmup Event Count Required**: `150000`
- **Warmup Events Discarded**: `150021`
- **Width**: `1280`

## Dataset Information

- **Shape:** `(1569914,)`
- **Dtype:** `[('x', '<u2'), ('y', '<u2'), ('t', '<u8'), ('p', 'u1')]`

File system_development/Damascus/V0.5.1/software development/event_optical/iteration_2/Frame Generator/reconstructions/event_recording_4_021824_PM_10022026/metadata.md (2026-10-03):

# event_recording_4_021824_PM_10022026

## Recording Metadata

- **Acquisition Mode**: `Continuous`
- **Arena Api Version**: `unknown`
- **Camera Model**: `TRT009S-E`
- **Duration Seconds**: `10.425666093826294`
- **Erc Enable**: `False`
- **Erc Rate Limit**: `20.0`
- **Event Format**: `EVT3_0`
- **Event Rate**: `96617.04019050497`
- **Height**: `720`
- **Recorded**: `021824_PM_10022026`
- **Recording Triggered**: `True`
- **Requested Stream Buffer Count**: `256`
- **Serial Number**: `250200198`
- **Software**: `Event Camera Recorder`
- **Software Version**: `0.2`
- **Stream Armed Duration Seconds**: `11.419373750686646`
- **Stream Auto Packet Size**: `True`
- **Stream Buffer Handling Mode**: `NewestOnly`
- **Stream Output**: `XYTPFrame`
- **Stream Packet Resend**: `True`
- **Total Buffers**: `8298`
- **Total Events**: `1007297`
- **Warmup Buffers Discarded**: `789`
- **Warmup Duration Seconds**: `0.9937076568603516`
- **Warmup Event Count Required**: `150000`
- **Warmup Events Discarded**: `150080`
- **Width**: `1280`

## Dataset Information

- **Shape:** `(1007297,)`
- **Dtype:** `[('x', '<u2'), ('y', '<u2'), ('t', '<u8'), ('p', 'u1')]`

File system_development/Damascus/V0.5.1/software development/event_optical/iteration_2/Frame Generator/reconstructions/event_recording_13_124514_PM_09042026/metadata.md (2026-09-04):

# event_recording_13_124514_PM_09042026

## Recording Metadata

- **Acquisition Mode**: `Continuous`
- **Arena Api Version**: `unknown`
- **Camera Model**: `TRT009S-E`
- **Duration Seconds**: `10.807171821594238`
- **Erc Enable**: `False`
- **Erc Rate Limit**: `20.0`
- **Event Format**: `EVT3_0`
- **Event Rate**: `60478.91259524568`
- **Height**: `720`
- **Recorded**: `124514_PM_09042026`
- **Serial Number**: `250200198`
- **Software**: `Event Camera Recorder`
- **Software Version**: `0.2`
- **Stream Auto Packet Size**: `True`
- **Stream Buffer Handling Mode**: `OldestFirst`
- **Stream Output**: `XYTPFrame`
- **Stream Packet Resend**: `True`
- **Total Buffers**: `11186`
- **Total Events**: `653606`
- **Width**: `1280`

## Dataset Information

- **Shape:** `(653606,)`
- **Dtype:** `[('x', '<u2'), ('y', '<u2'), ('t', '<u8'), ('p', 'u1')]`

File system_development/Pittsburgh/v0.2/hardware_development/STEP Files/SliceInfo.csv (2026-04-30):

Layer | Layer Height [mm] | Area [mm²] | Contours [mm] | Hatches [mm]
1 | -1.440 | 0.00 | 0.00 | 0.00
2 | -1.425 | 18.07 | 15.08 | 0.00
3 | -1.410 | 18.07 | 15.08 | 0.00
4 | -1.395 | 18.07 | 15.08 | 0.00
5 | -1.380 | 18.07 | 15.08 | 0.00
6 | -1.365 | 18.07 | 15.08 | 0.00
7 | -1.350 | 18.07 | 15.08 | 0.00
8 | -1.335 | 18.07 | 15.08 | 0.00
9 | -1.320 | 18.07 | 15.08 | 0.00
10 | -1.305 | 18.07 | 15.08 | 0.00
11 | -1.290 | 18.07 | 15.08 | 0.00
12 | -1.275 | 18.07 | 15.08 | 0.00
13 | -1.260 | 18.07 | 15.08 | 0.00
14 | -1.245 | 18.07 | 15.08 | 0.00
15 | -1.230 | 18.07 | 15.08 | 0.00
16 | -1.215 | 18.07 | 15.08 | 0.00
17 | -1.200 | 18.07 | 15.08 | 0.00
18 | -1.185 | 18.07 | 15.08 | 0.00
19 | -1.170 | 18.07 | 15.08 | 0.00
20 | -1.155 | 18.07 | 15.08 | 0.00
21 | -1.140 | 18.07 | 15.08 | 0.00
22 | -1.125 | 18.07 | 15.08 | 0.00
23 | -1.110 | 18.07 | 15.08 | 0.00
24 | -1.095 | 18.07 | 15.08 | 0.00
25 | -1.080 | 18.07 | 15.08 | 0.00
26 | -1.065 | 18.07 | 15.08 | 0.00
27 | -1.050 | 18.07 | 15.08 | 0.00
28 | -1.035 | 18.07 | 15.08 | 0.00
29 | -1.020 | 18.07 | 15.08 | 0.00
30 | -1.005 | 18.07 | 15.08 | 0.00
31 | -1.000 | 18.07 | 15.08 | 0.00
32 | -0.990 | 614.87 | 2807.33 | 0.00
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

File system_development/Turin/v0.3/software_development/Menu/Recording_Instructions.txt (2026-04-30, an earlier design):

metavision_viewer.exe 
  -Simple viewer to stream events from an event file or a device, using the SDK driver API.

  Error Fixing
	1. If you are getting errors try manually launching metavision_viewer.exe
	2. Ensure all hardware is plugged in correctly
	3. Ensure that all cords and POI injector can handle stream rate
	4. Adjust settings

Recording Options:
  -Define a region using the cursor (click and drag) to set a Region of Interest (ROI)
  -Press SPACE key while running to record or stop recording raw data
  -Press 'q' or Escape key to leave the program.
  -Press 'o' to toggle the on screen display.
  -Press 'l' to load the camera settings from the input camera config file.
  -Press 's' to save the camera settings to the output camera config file.
  -Press 'r' to toggle the hardware ROI mode (window mode or lines mode, default: window mode).
  -Press 'R' to toggle the ROI/RONI mode.
  -Press 'e' to toggle the ERC module (if available).
  -Press '+' to increase the ERC threshold (if available).
  -Press '-' to decrease the ERC threshold (if available).
  -Press 'h' to print this help.

Input Options:
  -h [ --help ]                         Produce help message.
  -s [ --serial ] arg                   Serial ID of the camera. This flag is
                                        incompatible with flag
                                        '--input-event-file'.
  -i [ --input-event-file ] arg         Path to input event file (RAW, DAT or
                                        HDF5). If not specified, the camera
                                        live stream is used.
  -j [ --input-camera-config ] arg      Path to a JSON file containing camera
                                        config settings to restore a camera
                                        state. Only works for live cameras.
  -b [ --biases ] arg                   Path to a biases file. If not
                                        specified, the camera will be
                                        configured with the default biases.
  -o [ --output-file ] arg (=data.raw)  Path to an output file used for data
                                        recording. Default value is 'data.raw'.
                                        It also works when reading data from a
                                        file.
  --output-camera-config arg (=settings.json)
                                        Path to a JSON file where to save the
                                        camera config settings. Default value
                                        is 'settings.json'. Only works for live
                                        camera.
  -r [ --roi ] arg                      Hardware ROI to set on the sensor in
                                        the format [x y width height].

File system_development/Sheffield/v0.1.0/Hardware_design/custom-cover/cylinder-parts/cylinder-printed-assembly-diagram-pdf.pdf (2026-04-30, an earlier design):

# Cylinder Assembly Chopped

## The following is designed… - to be used with M8 Socket Head Bolts of ~3cm length and M8 Lock Nuts - and to be printed on a 235x235mm 3D printer bed

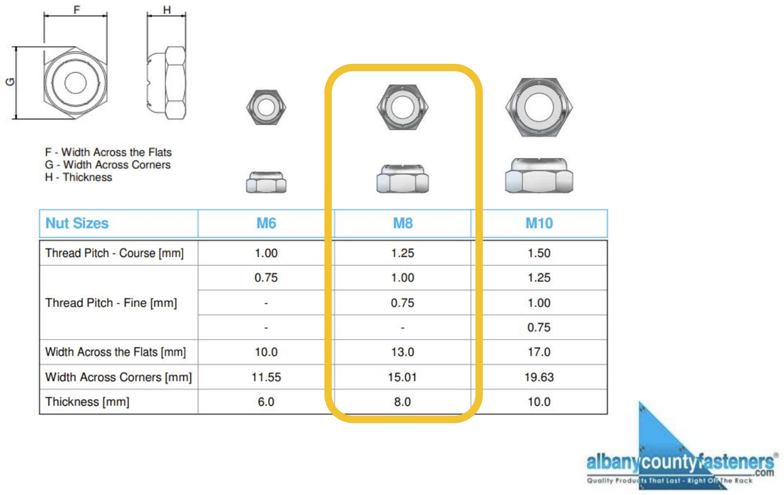
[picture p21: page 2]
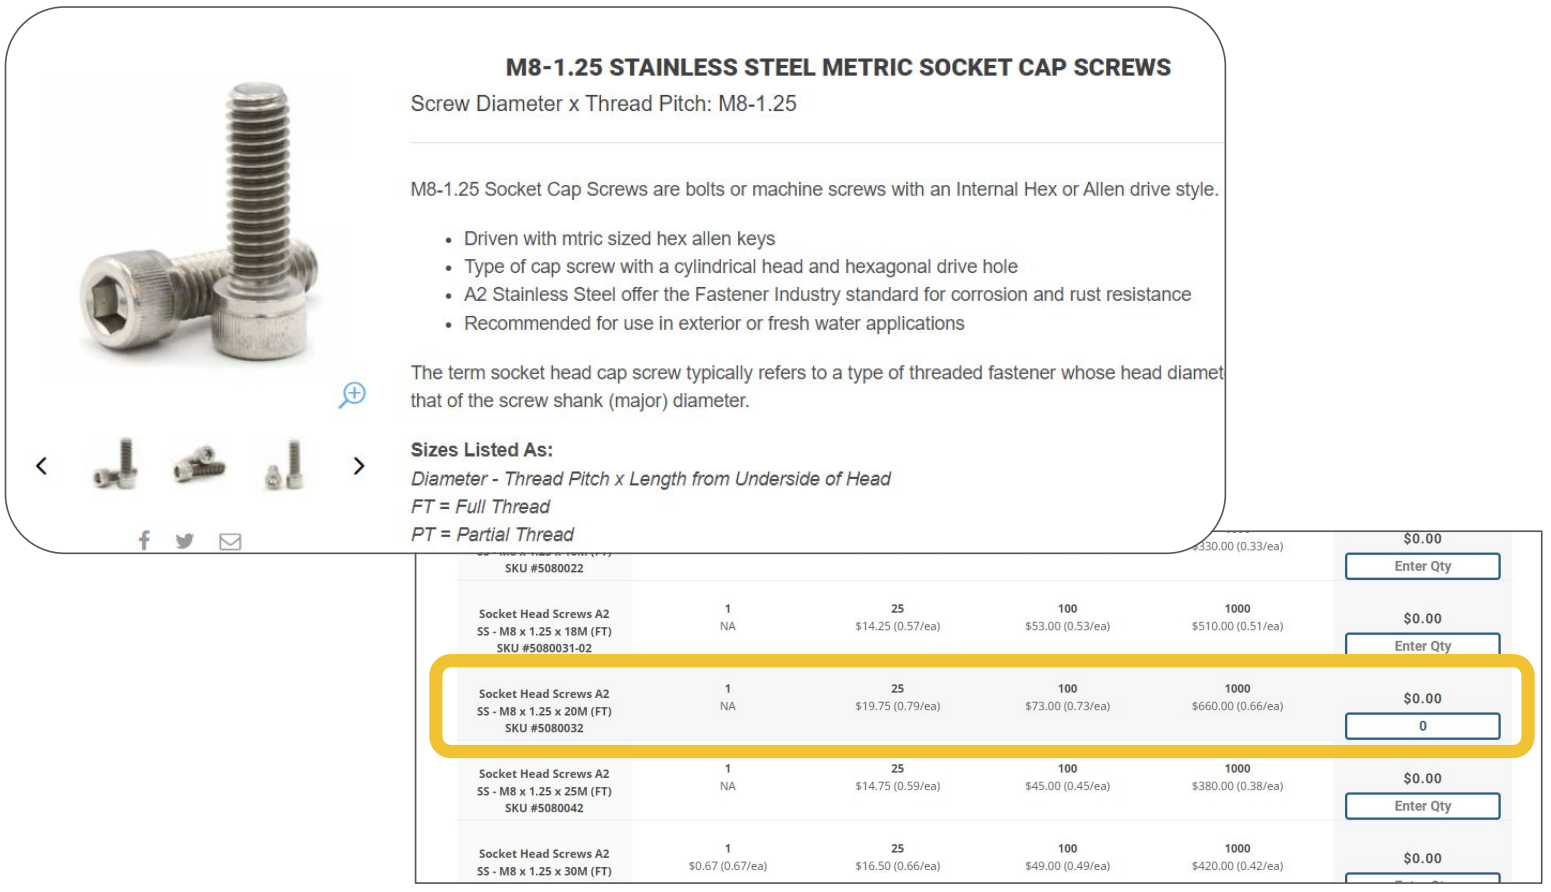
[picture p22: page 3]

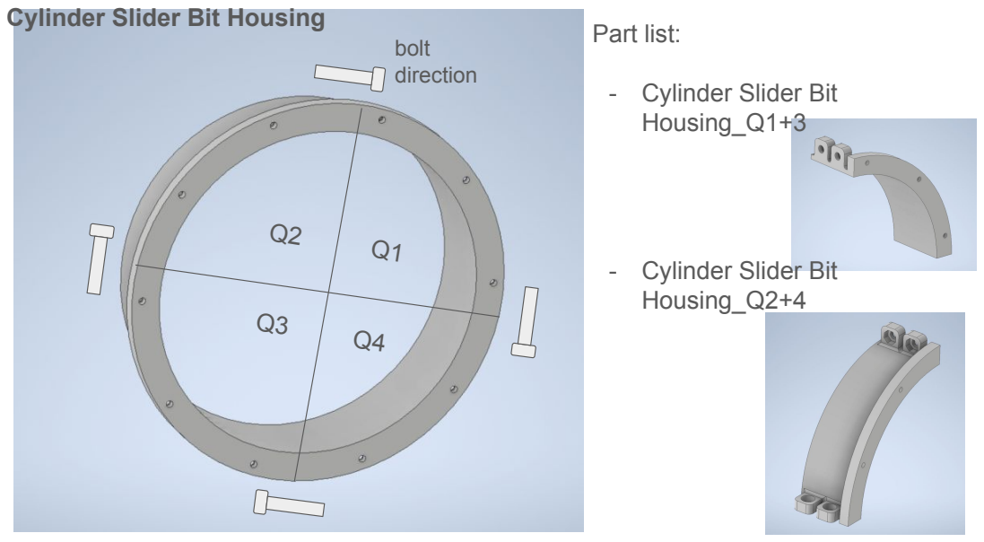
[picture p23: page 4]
Part list:; bolt direction

Cylinder Slider Bit Housing

- Cylinder Slider Bit
Housing_Q1+3

Housing_Q2+4

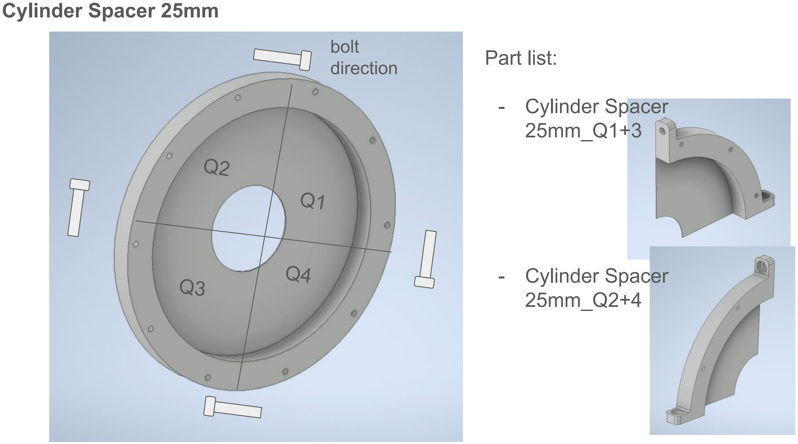
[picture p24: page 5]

Q1

Q2

Q3

Q4

Part list:

- Cylinder Spacer
25mm_Q1+3
- Cylinder Spacer
25mm_Q2+4

bolt
direction

Cylinder Spacer 25mm

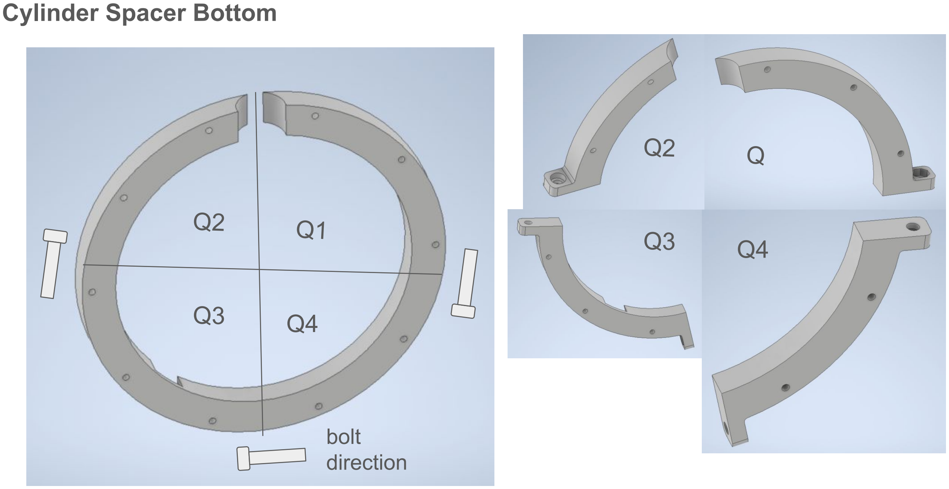
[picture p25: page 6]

Q2 Q1

Q3 Q4

bolt
direction

Q2 Q

Q3 Q4

Cylinder Spacer Bottom

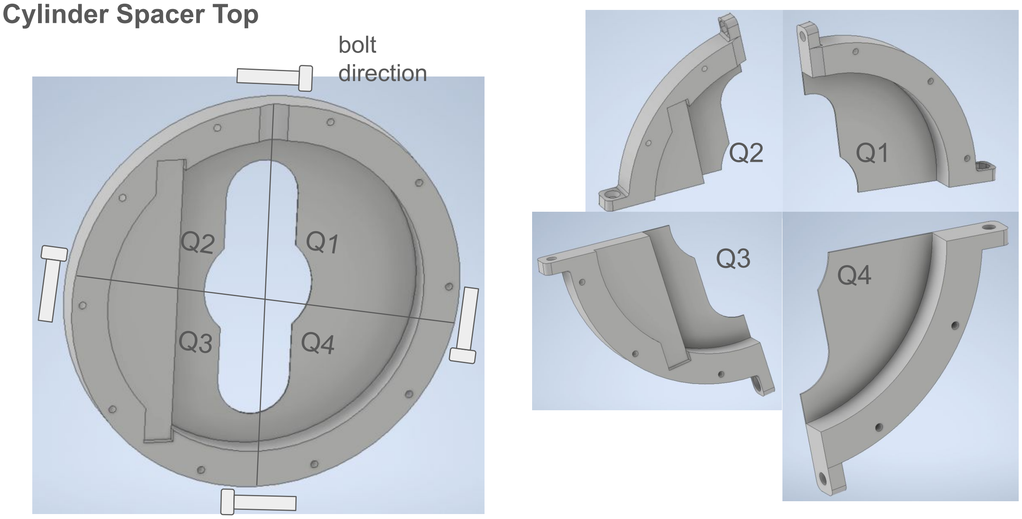
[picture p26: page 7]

Q2

Q1

Q3
Q4

bolt
direction
Q2 | Q1

Q3 Q4

Cylinder Spacer Top

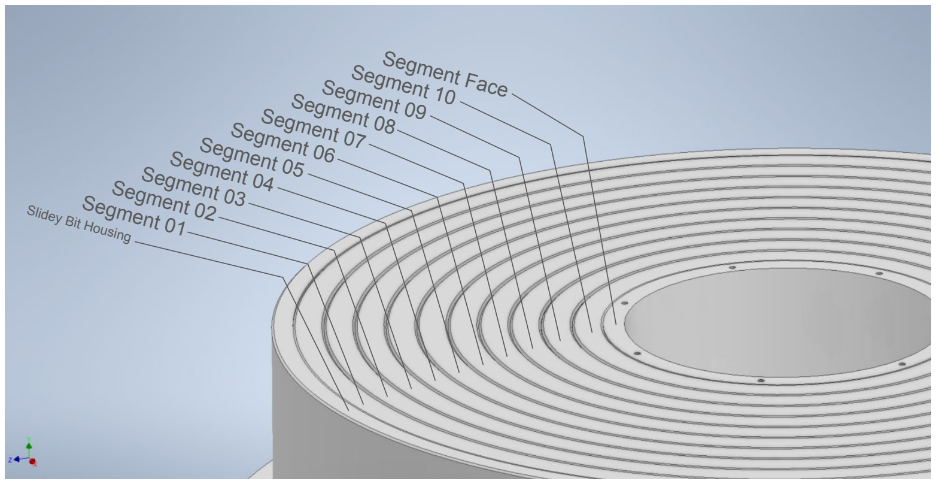
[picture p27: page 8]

Segment Face
Segment 10

Segment 07
Segment 06
Segment 05
Segment 04
Segment 03
Segment 02
Segment 01

Segment 09
Segment 08

Slidey Bit Housing

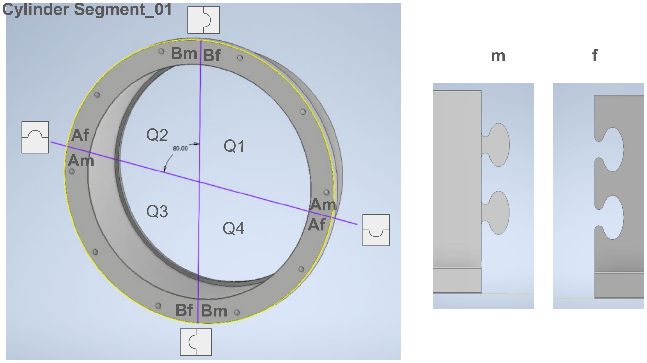
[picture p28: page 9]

Cylinder Segment_01

Q1 Q2

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
Bf Bm

m | f

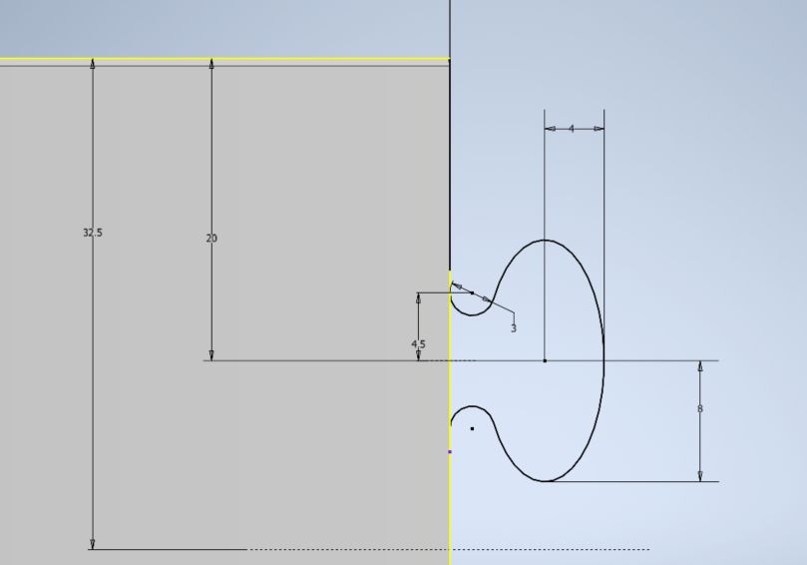
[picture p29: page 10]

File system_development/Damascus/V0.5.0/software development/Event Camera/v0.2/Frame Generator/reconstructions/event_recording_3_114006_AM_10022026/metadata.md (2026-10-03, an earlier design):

# event_recording_3_114006_AM_10022026

## Recording Metadata

- **Acquisition Mode**: `Continuous`
- **Arena Api Version**: `unknown`
- **Camera Model**: `TRT009S-E`
- **Duration Seconds**: `9.778547286987305`
- **Erc Enable**: `False`
- **Erc Rate Limit**: `20.0`
- **Event Format**: `EVT3_0`
- **Event Rate**: `4917.7038867514175`
- **Height**: `720`
- **Recorded**: `114006_AM_10022026`
- **Recording Triggered**: `True`
- **Requested Stream Buffer Count**: `512`
- **Serial Number**: `250200198`
- **Software**: `Event Camera Recorder`
- **Software Version**: `0.2`
- **Stream Armed Duration Seconds**: `63.701659202575684`
- **Stream Auto Packet Size**: `True`
- **Stream Buffer Handling Mode**: `OldestFirst`
- **Stream Output**: `XYTPFrame`
- **Stream Packet Resend**: `True`
- **Total Buffers**: `10314`
- **Total Events**: `48088`
- **Warmup Buffers Discarded**: `36247`
- **Warmup Duration Seconds**: `53.92311191558838`
- **Warmup Event Count Required**: `150000`
- **Warmup Events Discarded**: `150009`
- **Width**: `1280`

## Dataset Information

- **Shape:** `(48088,)`
- **Dtype:** `[('x', '<u2'), ('y', '<u2'), ('t', '<u8'), ('p', 'u1')]`

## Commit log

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2026-03-17 updated code, can see temperature now.
    [Kennlinie_combined.csv]
2026-03-17 updated code
    [Run 6_frame314_Unconverted.csv, Run6_frame314.csv]
2026-03-18 updated program
    [Kennlinie_combined.csv]
2026-03-24 Mithril Parts and Galvo Documentation
    [Adapter.ipt, Adapter.stp, Cylinder - Inner.0007.ipt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]
2026-03-26 Mithril Parts and Folder Organization
    [12mm Cover.ipt, Access Cap.stp, Base Cylinder Housing.ipt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]
2026-03-30 Vibrometer Cover
    [12mm Cover.ipt, Build Plate.0005.ipt, Build Plate.ipt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]
2026-03-30 Vibrometer Housing Assembly
    [Mithril Center Cylinder.ipt, Vibrometer Cover.0001.iam, Vibrometer Cover.iam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]
2026-04-01 New Vibrometer Housing
    [Head Plate Insert.0017.ipt, Head Plate Insert.ipt, Vibrometer Cover.0001.iam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]
2026-04-13 removed redundant thermal software file and updated code
    [Kennlinie_combined.csv, Run 6_frame314_Unconverted.csv, Run10_frame350.csv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]
2026-04-16 Vibrometer Perpendicular Rig
    [12mm Cover.ipt, 2020 Legs (160mm).0011.ipt, 2020 Legs (160mm).ipt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]
2026-04-30 Vibrometer Data
    [VIBROMETER SCAN SETTINGS.xlsx]
2026-04-30 updated variations names
    [001_CABINET_U_HANDLE_ASM.iam, 090869.ipt, 090870.ipt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]
2026-05-01 Update the housing and assembly
    [Assembly of Cover+Plate+Event Camera.iam, Turin Camera Cylinder Housing.ipt]
2026-05-02 Updated Damascus
    [12mm Cover.ipt, 35mmLens.ipt, Antireflective Glass.ipt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]
2026-05-02 Damascus GCODE
    [damascusAssembly.3mf, damascusCoverAssembly.0005.iam, damascusCoverAssembly.0006.iam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]
2026-05-05 Updated cylinder
    [Damascus Center Cylinder.0011.ipt, Damascus Center Cylinder.ipt, Damascus Center Cylinder.stp]
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2026-05-12 Updated Damascus model
    [damascusCoverAssembly.0006.iam, damascusCoverAssembly.0007.iam, damascusCoverAssembly.iam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]
2026-05-13 Damascus cover
    [twinHead - Copy.0031.ipt, twinHead - Copy.ipt]
2026-05-16 Updated Model and Chamfer
    [12mm Turin Cover.ipt, 316 Stainless Steel General Purpose Washer.ipt, Assembly of Cover+Plate+Event Camera.0046.iam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]
2026-05-19 code for thermal camera
2026-05-22 updated twin head model
    [12mm Cover.0009.ipt, 12mm Cover.ipt, Camera with 35mm.0006.iam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]
2026-05-27 Changed model like 4 times
    [Bolt Slot Covers.0001.ipt, Bolt Slot Covers.ipt, Bolt Slot Covers.stp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]
2026-05-29 Updated Model
    [Bolt Slot Covers.0001.ipt, Bolt Slot Covers.0002.ipt, Bolt Slot Covers.ipt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]
2026-06-01 updating lid
    [damascusCoverAssembly.0014.iam, damascusCoverAssembly.0015.iam, damascusCoverAssembly.iam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]
2026-06-02 new folder
    [12mm Cover.ipt, 35mmLens.ipt, Antireflective Glass.ipt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]
2026-06-03 Fixed Model
    [Dual Camera Base.0061.ipt, Dual Camera Base.0062.ipt, Dual Camera Base.ipt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]
2026-06-05 Made the lid for damascus thiccer
    [Bolt Slot Covers.0007.ipt, Bolt Slot Covers.0009.ipt, Bolt Slot Covers.ipt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]
2026-06-05 wire plugs
    [WirePlugs.0005.ipt, WirePlugs.0006.ipt, WirePlugs.ipt]
2026-06-05 new strp files
    [Bolt Slot Covers.stp, Dual Camera Base.stp]
2026-06-14 deprecated few old styles
    [090869.ipt, 090870.ipt, 090879-XX_090879-04.ipt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]
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2026-06-30 BOM update
    [BOM-Damascus-V0.5.xlsx]
2026-07-02 added x.x.0 to the version names
    [12mm Cover.0009.ipt, 12mm Cover.ipt, 35mmLens.ipt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]
2026-07-02 Readme instructions for reducing event camera killing
    instructions so that event camera stops dying and being lame to the user. Media file and images are also included to help the user select the correct setting.
2026-07-02 Updated image and read me for the event camera stuff
    Further instructions to verity the stability of the event camera during the viewing of preview footage. The camera should not be a meanie at this point hopefully
2026-07-06 read me lol
    instructions to install the python api for the event camera. it is for the arena sdk and has a specific way it needs to be installed or it will be a meanie to you, so watch out
    [Dual Camera Base v2.3mf]
2026-07-13 updated models
    [damascusCoverAssembly.0021.iam, damascusCoverAssembly.0022.iam, damascusCoverAssembly.iam]
2026-07-20 changed some models lol
    [Damascus Center Cylinder.0012.ipt, Damascus Center Cylinder.ipt, Damascus Center Cylinder.stp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]
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2026-07-29 Python file to record event camera feed
2026-07-29 Updated event camera code
    Changed file path handling to allow for any user to simply start code
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2026-07-30 REcording for event camera works
2026-07-31 updated event camera code
2026-08-14 8/14/2026 welding
    Testing threshold settings
2026-08-17 Moved and deleted Uru folder
    [300mm Housing 1.ipt, 300mm housing 2 Camera.ipt, C .Replace - 10.ipt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]
2026-08-17 added v0.x.0 to a version setup
    [001_CABINET_U_HANDLE_ASM.iam, 1078N152_Class 10.9 High-Strength Steel Threa.ipt, 11-4310.ipt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]
2026-08-28 Event Camera Test Params XLSX
    [Event Camera Test Parameters.xlsx, VIBROMETER SCAN SETTINGS.xlsx, pyvenv.cfg]
2026-08-31 data file 0 8_31
    [Event Camera Test Parameters.xlsx]
2026-09-02 Changed code for event camera to allow for buffer size changing
2026-09-18 9/4/26 Test Data
    [Event Camera Test Parameters.xlsx]
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2026-10-02 setting up 0v.5.1
    [12mm Cover.ipt, 35mmLens.ipt, Antireflective Glass.ipt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]
2026-10-02 VIs and Data Iterations Organized
    [12mm Cover.ipt, 2020 Legs (70mm).0011.ipt, 2040 Legs (263.5mm).0012.ipt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]
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2026-10-15 thermal-optical VIs update
    Individual VIs for thermal & optical camera are added.
2026-10-19 thermal optical v12 updates
    individual camera speed check
2026-10-20 Add Python 3.12 Metavision RAW recorder and setup scripts
    Verify camera capture and smooth RAW playback. Vendor shutdown crash and EVT3 decoder warnings remain unresolved.
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2026-10-23 camera format configure from camera node
    work in progress
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
